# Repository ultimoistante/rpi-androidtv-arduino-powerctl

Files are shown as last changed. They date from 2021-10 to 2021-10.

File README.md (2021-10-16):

# RaspberryPi 4 Android TV with Arduino-based PowerController
This repository contains the source code, all schematics and some words on the build process of a custom AndroidTV device I've built with a RaspberryPi4 SBC, an Arduino Nano, and a case of an old Technicolor TG582n ADSL modem.

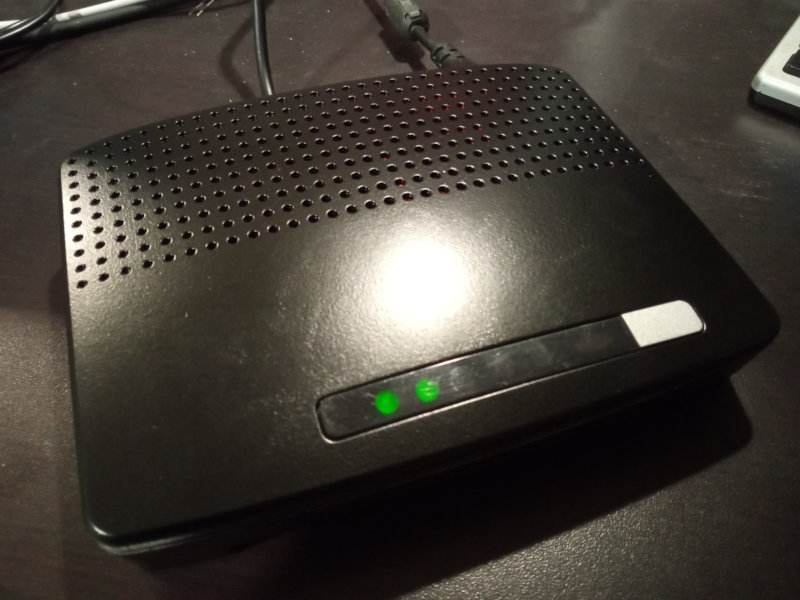
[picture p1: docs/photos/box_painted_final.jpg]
final version final painted box


## Arduino PowerController features
- handles RaspberryPi power via relay;
- does case cooling controlling a fan with PWM, reading temperature with a thermistor;
- since it's connected to RaspberryPi via UART, it can detect when android system is full booted, and can send shutdown command to it when user presses power button. After some seconds, cuts RaspberryPi power deactivating relay;
- drives the leds on the original modem board using different patterns for standby, booting and shutdown phases (I've reused a slice of the original modem pcb, cut with a grinder);

## Arduino code
The arduino code is very simple, and is built with PlatformIO on VisualStudio Code. All the code is in src/main.cpp.
I tried to do my best to make code very clean and simple, and with full comments.

## AndroidTV system setup
I've downloaded and installed LineageOS 18.1 Android TV (Android 11) (by KonstaGANG): https://konstakang.com/devices/rpi4/LineageOS18-ATV/
I've installed it on a 32GB microSD.

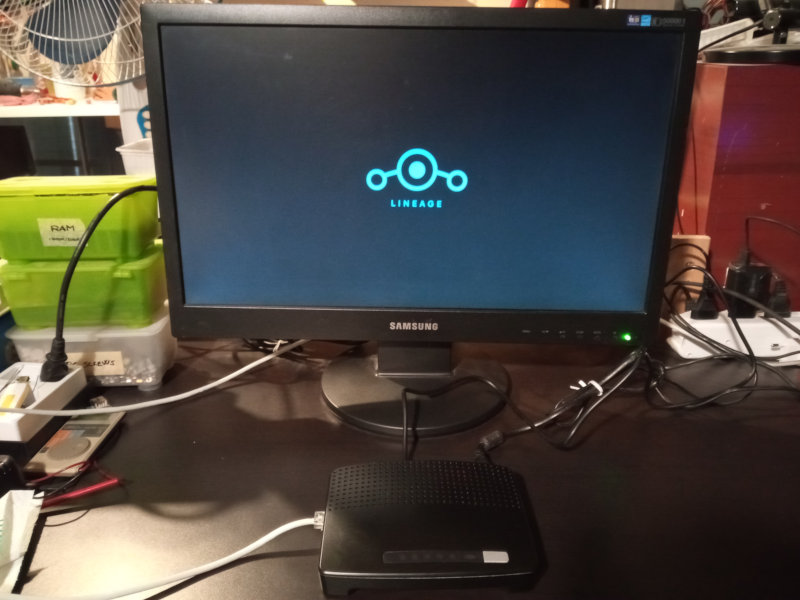
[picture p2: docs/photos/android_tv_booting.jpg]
android-tv booting

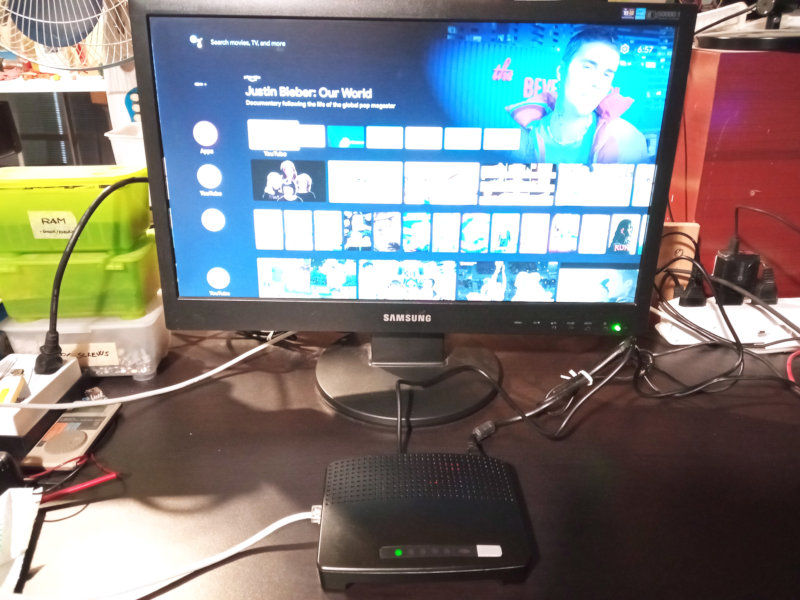
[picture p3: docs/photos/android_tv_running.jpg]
android-tv running


## Case adaptations
I had this old modem, found some time ago in local dumpster. It's perfect for my needs (right dimensions, nice looking design, and many ventilation holes, all around case).

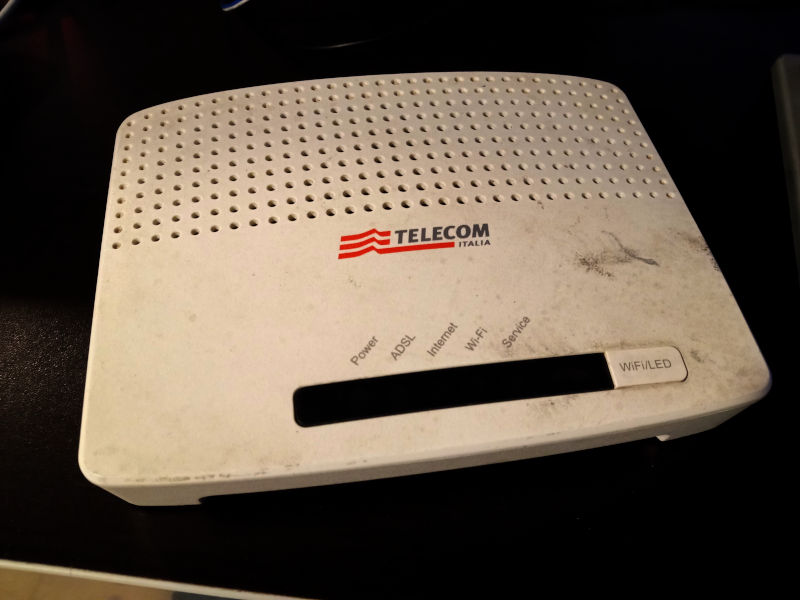
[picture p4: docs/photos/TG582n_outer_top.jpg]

*case donor device, an old Technicolor TG582n, coming from the dumpster*

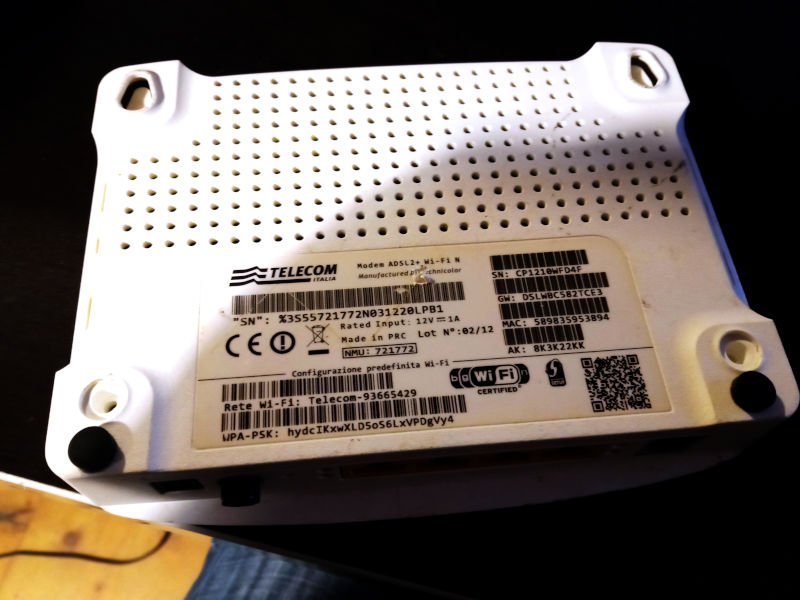
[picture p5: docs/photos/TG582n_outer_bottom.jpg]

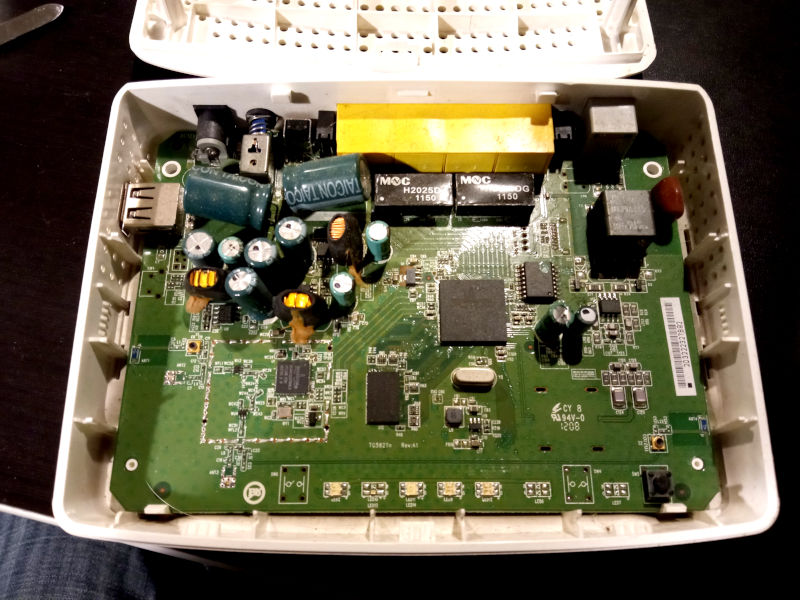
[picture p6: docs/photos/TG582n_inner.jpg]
device inner pcb

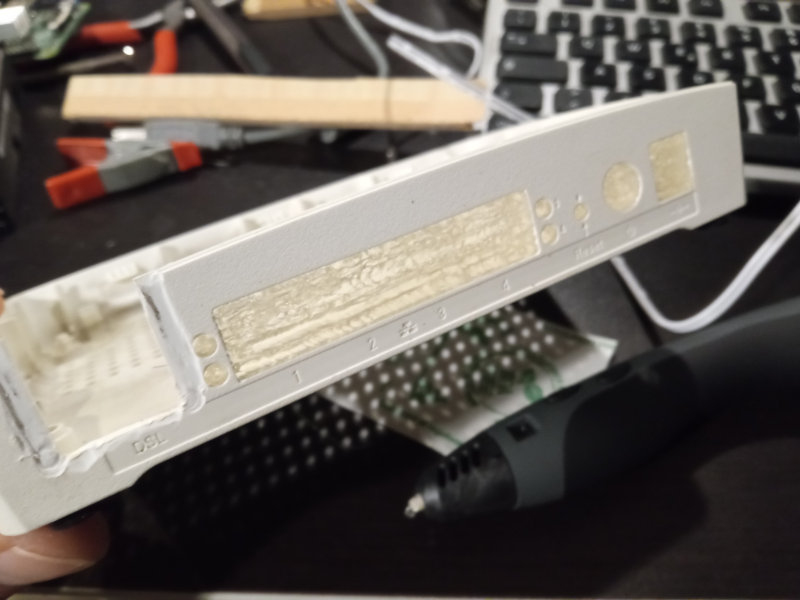
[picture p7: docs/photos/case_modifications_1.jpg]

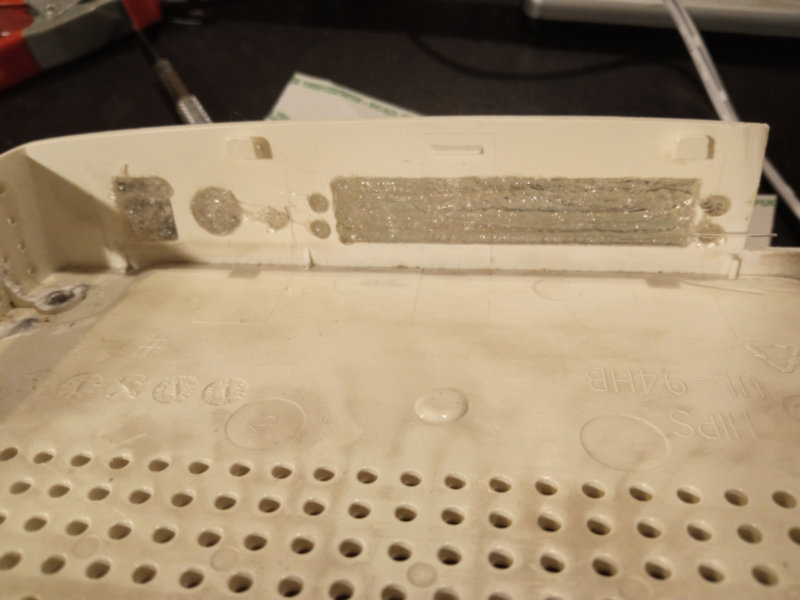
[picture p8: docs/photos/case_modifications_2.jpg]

*filled unneeded holes with a 3D pen*
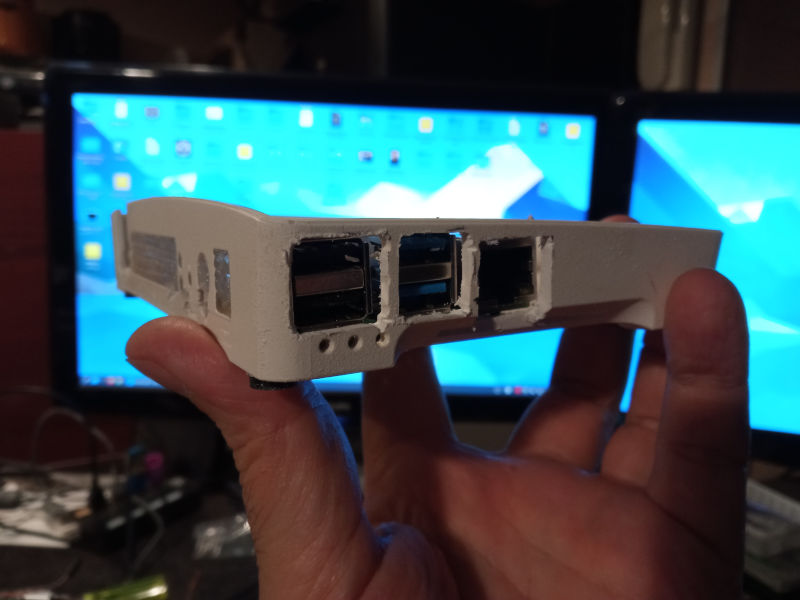
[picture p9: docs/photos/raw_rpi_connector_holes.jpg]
raw rpi connetor holes

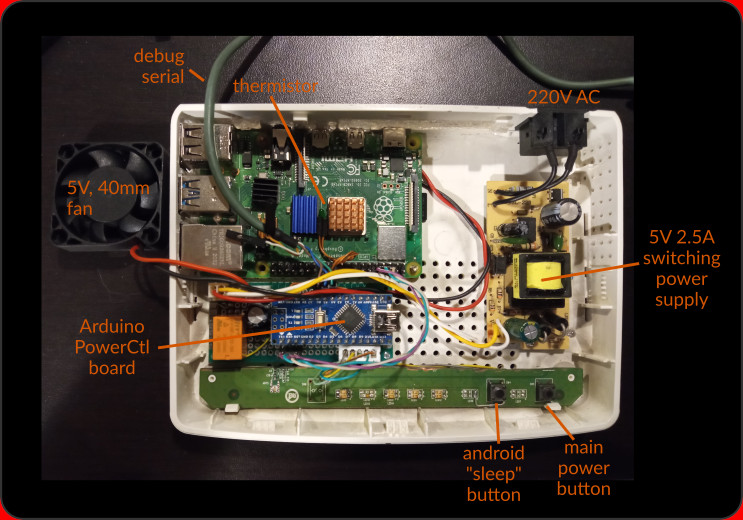
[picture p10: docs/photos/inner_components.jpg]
inner view

*NOTE: android sleep button is connected to GPIO21/GND on RaspberryPi. Sorry, not shown in photo. See FAQs on konstaGANG page)*
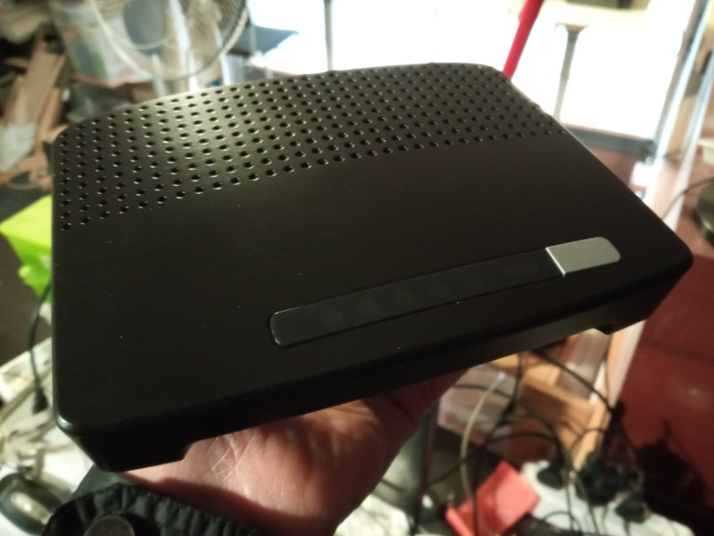
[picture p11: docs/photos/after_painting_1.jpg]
after painting

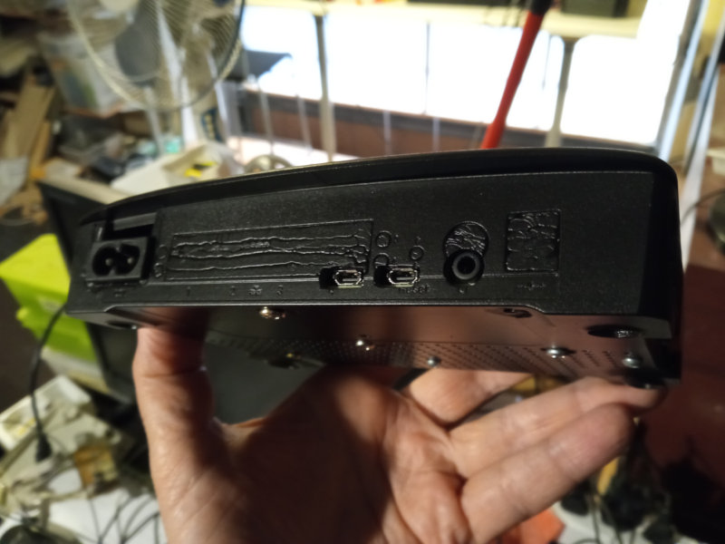
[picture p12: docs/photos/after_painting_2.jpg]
after painting


### Original modem PCB modifications
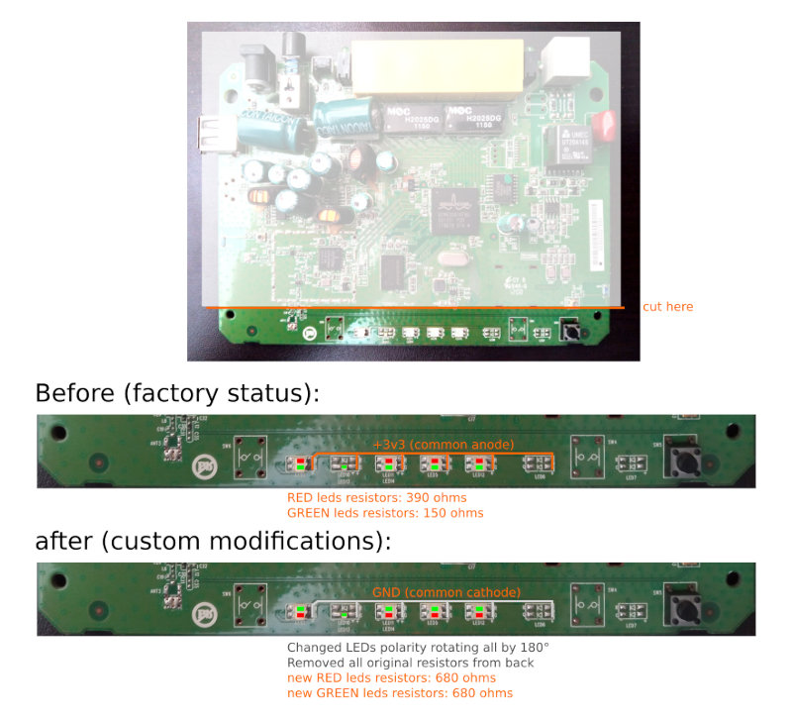
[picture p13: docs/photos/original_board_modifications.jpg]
original board modifications


### Complete circuit schematics
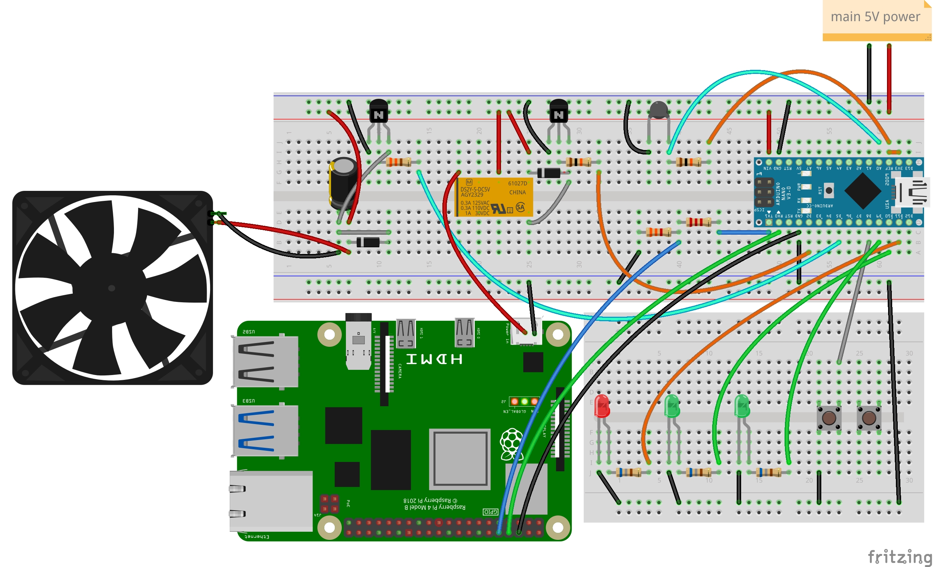
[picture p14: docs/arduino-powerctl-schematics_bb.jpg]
complete schematics

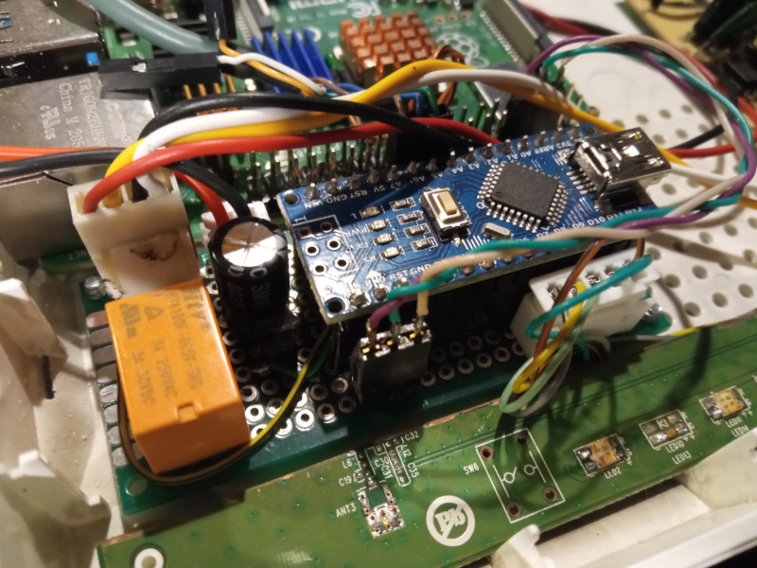
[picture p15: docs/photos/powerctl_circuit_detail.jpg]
powerctl board

Note:
 - for fan control, i've used a C2001 NPN transistor (Ic=700mA), and capacitor is 1000uF 16V (to avoid pwm audible noise);
 - relay is 5V 3A, driver transistor is a generic NPN (i.e: BC547);
 - thermistor is a 10K type;
 - on Arduino TX there is a level converter made with a voltage divider (R1: 2k2, R2: 3k3), to avoid damage on RaspberryPi UART;

(fritzing and pdf files are under docs/ directory)

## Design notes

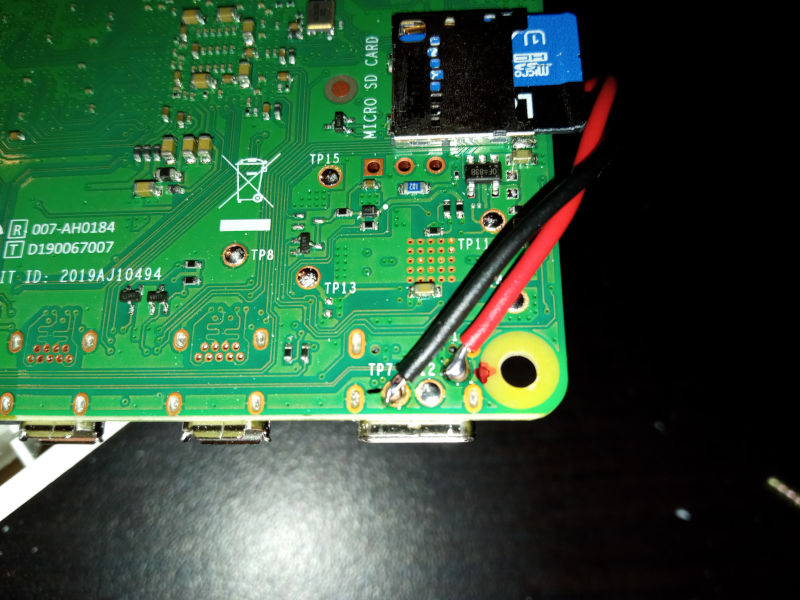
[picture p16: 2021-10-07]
docs/photos/rpi4_power_pads.jpg

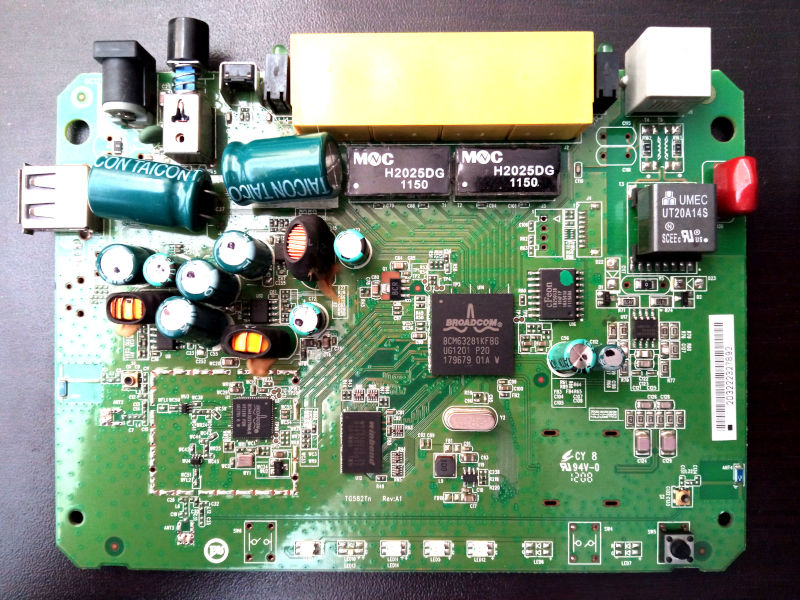
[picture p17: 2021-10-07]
docs/photos/TG582n_board.jpg

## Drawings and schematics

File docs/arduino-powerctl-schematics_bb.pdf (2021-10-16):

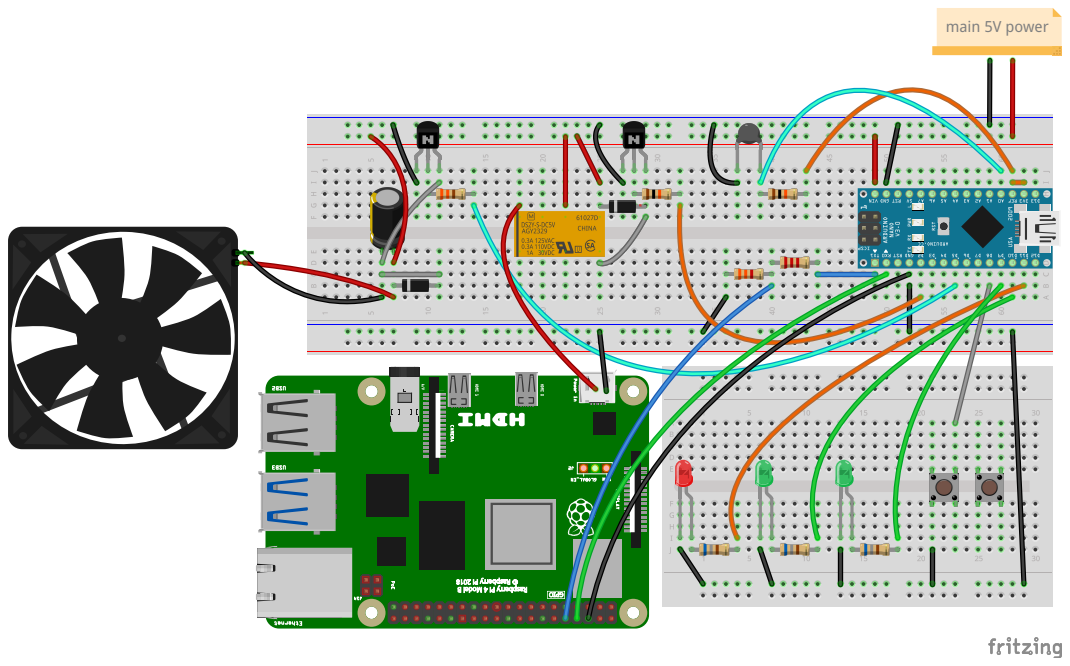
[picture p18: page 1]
main 5V power

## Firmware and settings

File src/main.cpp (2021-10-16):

/** RaspberryPi/AndroidTV Arduino Power Control device
 **
 ** This device implements power control features for RaspberryPi4 AndroidTV mediacenter.
 ** Its main feature is to control power supply to RaspberryPi through a relay.
 ** Communicates with RaspberryPi via UART connection, sending commands (i.e.: shutdown).
 ** It also controls case fan throttling reading RaspberryPi CPU temperature using a thermistor.
 **
 ** Author: Salvatore Carotenuto of OpenMakersItaly, aka ultimoistante
 **
 ** Credits:
 **   Temperature reading code taken from: https://learn.adafruit.com/thermistor/using-a-thermistor
 **/

 // -----------------------------------------------------------------------------
 // -----------------------------------------------------------------------------
 //
 // Arduino Nano connections
 //                                       +-----+
 //                                 +-----|=====|-----+
 //                      D13 [PB5]  |o    |=====|    o|  [PB4] D12
 //                            3v3  |o    +-----+    o| ~[PB3] D11 ---> (standby) status LED (red)
 //                           Vref  |o               o| ~[PB2] D10 ---> (power on) status LED (green)
 //       thermistor <--- A0 [PC0]  |o               o| ~[PB1] D9  ---> serial activity LED
 //                       A1 [PC1]  |o               o|  [PB0] D8  ---> power button
 //                       A2 [PC2]  |o               o|  [PD7] D7  
 //                       A3 [PC3]  |o    Arduino    o| ~[PD6] D6
 //  debug serial RX <--- A4 [PC4]  |o      Nano     o| ~[PD5] D5  ---> fan speed throttle
 //  debug serial TX <--- A5 [PC5]  |o               o|  [PD4] D4  
 //                      A6 [ADC6]  |o               o| ~[PD3] D3  
 //                      A7 [ADC7]  |o               o|  [PD2] D2  ---> RaspberryPi power relay control
 //                             5V  |o               o|  GND
 //                      RST [PC6]  |o               o|  [PC6] RST
 //                            GND  |o     . . .     o|  [PD0] RX  ---> to RaspberryPi TXD (pin  8 - GPIO14)
 //                            Vin  |o     . . .     o|  [PD1] TX  ---> to RaspberryPi RXD (pin 10 - GPIO15)
 //                                 +-----------------+
 //
 // -----------------------------------------------------------------------------
 // -----------------------------------------------------------------------------


#include <Arduino.h>
#include <SoftwareSerial.h>
#include <AceButton.h>
using namespace ace_button;
#include <jled.h>


// -----------------------------------------------------------------------------


#define THERMISTOR_PIN                A0
#define STATUS_LED_RED_PIN            11
#define STATUS_LED_GREEN_PIN          10
#define UART_ACT_LED_PIN              9
#define POWER_BUTTON_PIN              8
#define FAN_THROTTLE_PIN              5
#define RELAY_PIN                     2
#define SW_SERIAL_RX_PIN              A4
#define SW_SERIAL_TX_PIN              A5

#define THERMISTOR_SERIES_RESISTOR    10000 // the value of the 'other' resistor in voltage divider
#define THERMISTOR_NOMINAL_R          10000 // nominal thermistor resistance at 25 degrees C
#define THERMISTOR_NOMINAL_TEMP       25    // thermistor nominal resistance temperature (almost always 25 C)
#define THERMISTOR_BETA_COEFFICIENT   3950  // thermistor beta coefficient (usually 3000-4000)
#define TEMPERATURE_READ_SAMPLES      5     // how many samples to take and average, more takes longer, but is more 'smooth'

#define HW_SERIAL_BAUDRATE            115200
#define SW_SERIAL_BAUDRATE            57600

// uncomment this line to dump android serial on debug serial
// #define DUMP_TO_DEBUG_SERIAL

#define READ_TEMPERATURE_INTERVAL           2500
#define FAN_THROTTLE_MIN_TEMP               30.0
#define FAN_THROTTLE_MIN_TEMP_HYSTERESIS    2.0
#define FAN_THROTTLE_MAX_TEMP               50.0
#define FAN_THROTTLE_MIN_PWM                16
#define FAN_THROTTLE_MAX_PWM                255
float currentTemperature = 0;
unsigned long next_read_temperature_time = 0;
unsigned char fan_was_activated = 0;

#define POWER_BUTTON_LONGPRESS_DELAY        2000

#define SHUTDOWN_GRACE_TIME_MSECS           10000

#define STATUS_STANDBY                  0
#define STATUS_BOOTING                  1
#define STATUS_ON                       2
#define STATUS_SHUTDOWN                 3
unsigned char currentStatus = STATUS_STANDBY;

// these are the strings to wait from android boot log, to detect when device is full booted.
// Arduino device goes in "STATUS_ON" when receives one of these strings.
#define ANDROID_BOOT_COMPLETE_LOG_LINE      "sdcardfs: dev_name -> /data/media"
#define ANDROID_BOOT_COMPLETE_LOG_LINE_ALT  "app=com.google.android.apps.mediashell"
// this is the string to wait from android boot log, to detect when device has completed shutdown
#define ANDROID_SHUTDOWN_COMPLETE_LOG_LINE  "reboot: Power down"

// debug (software) serial
SoftwareSerial debugSerial(SW_SERIAL_RX_PIN, SW_SERIAL_TX_PIN); // RX, TX

// status leds
auto standbyStatusLed = JLed(STATUS_LED_RED_PIN);
auto poweronStatusLed = JLed(STATUS_LED_GREEN_PIN);

// power button
AceButton powerButton(POWER_BUTTON_PIN);

#define MAX_SERIAL_BUFFER   511
char serialBuffer[MAX_SERIAL_BUFFER + 1];
unsigned int serialBufferIndex = 0;

volatile unsigned char interruptCounter = 0;

unsigned long shutdown_grace_time = 0;


// ----------------------------------------------------------------------------


// Interrupt handler called once a millisecond
SIGNAL(TIMER0_COMPA_vect)
    {
    interruptCounter++;
    if (interruptCounter == 50) // updates leds every 50msecs
        {
        standbyStatusLed.Update();
        poweronStatusLed.Update();
        interruptCounter = 0;
        }
    }


// ----------------------------------------------------------------------------


float readTemperature()
    {
    float average = 0.0;
    // take N samples in a row, with a slight delay
    for (uint8_t i = 0; i < TEMPERATURE_READ_SAMPLES; i++)
        {
        average += analogRead(THERMISTOR_PIN);
        delay(10);
        }
    average /= TEMPERATURE_READ_SAMPLES;

    // convert the value to resistance
    average = 1023 / average - 1;
    average = THERMISTOR_SERIES_RESISTOR / average;

    float steinhart;
    steinhart = average / THERMISTOR_NOMINAL_R;            // (R/Ro)
    steinhart = log(steinhart);                            // ln(R/Ro)
    steinhart /= THERMISTOR_BETA_COEFFICIENT;              // 1/B * ln(R/Ro)
    steinhart += 1.0 / (THERMISTOR_NOMINAL_TEMP + 273.15); // + (1/To)
    steinhart = 1.0 / steinhart;                           // Invert
    steinhart -= 273.15;                                   // convert absolute temp to C
    //
    return steinhart;
    }



// ----------------------------------------------------------------------------


// computes fan pwm value, based on temperature read. Also handles shutdown hysteresis.
// Temperature to PWM mapping is similar to arduino "map" function:
//    long map(long x, long in_min, long in_max, long out_min, long out_max) {
//        return (x - in_min) * (out_max - out_min) / (in_max - in_min) + out_min;
//    }
// 
unsigned char computeFanPwm(float temperature)
    {
    unsigned char pwmValue = 0;
    float minTemp = fan_was_activated ? (FAN_THROTTLE_MIN_TEMP - FAN_THROTTLE_MIN_TEMP_HYSTERESIS) : FAN_THROTTLE_MIN_TEMP;
    float maxTemp = FAN_THROTTLE_MAX_TEMP;
    //
    if (temperature <= minTemp)
        {
        pwmValue = 0;
        fan_was_activated = 0;
        }
    else
        {
        fan_was_activated = 1;
        //
        if (temperature >= maxTemp)
            pwmValue = FAN_THROTTLE_MAX_PWM;
        else
            {
            if (temperature > minTemp && temperature < maxTemp)
                {
                float mappedValue = (temperature - minTemp) * (FAN_THROTTLE_MAX_PWM - FAN_THROTTLE_MIN_PWM) / (maxTemp - minTemp) + FAN_THROTTLE_MIN_PWM;
                pwmValue = int(mappedValue);
                }
            }
        }
    //
    return pwmValue;
    }


// ----------------------------------------------------------------------------


void updateCurrentStatus(unsigned char newStatus)
    {
    currentStatus = newStatus;
    switch (currentStatus)
        {
            case STATUS_STANDBY:
                standbyStatusLed.Breathe(5000).Forever();
                poweronStatusLed.Off();
                digitalWrite(RELAY_PIN, LOW);
                break;
            case STATUS_BOOTING:
                standbyStatusLed.Blink(25, 250).Forever();
                poweronStatusLed.Blink(25, 250).Forever();
                digitalWrite(RELAY_PIN, HIGH);
                break;
            case STATUS_ON:
                standbyStatusLed.Off();
                poweronStatusLed.Breathe(2000).Forever();
                break;
            case STATUS_SHUTDOWN:
                standbyStatusLed.Blink(25, 250).Forever();
                poweronStatusLed.Off();
                // sends shutdown command to android device
                Serial.println("reboot -p");
                break;
        }
    }


// -----------------------------------------------------------------------------


void handleButtonEvent(AceButton* button, uint8_t eventType, uint8_t /*buttonState*/)
    {
    switch (eventType)
        {
        // handles "released" event as a "pressed" event, to distiguish it from a "long pressed" event
            case AceButton::kEventReleased:
                debugSerial.println("[I] button pressed");
                if (currentStatus == STATUS_STANDBY)
                    updateCurrentStatus(STATUS_BOOTING);
                else if (currentStatus == STATUS_ON)
                    updateCurrentStatus(STATUS_SHUTDOWN);
                break;
                // 
            // handles "long pressed" event
            case AceButton::kEventLongPressed:
                debugSerial.println("[I] button LONG pressed");
                // emergency shutdown: returns to STATUS_STANDBY (deactivates relay)
                if (currentStatus != STATUS_STANDBY)
                    updateCurrentStatus(STATUS_STANDBY);
                break;
        }
    }


// ----------------------------------------------------------------------------



void setup()
    {
    // for more stable readings, AREF pin is connected to 3.3V, so we set analogReference to EXTERNAL
    analogReference(EXTERNAL);
    //
    // sets USER_BUTTON_PIN as input, with pullup
    pinMode(POWER_BUTTON_PIN, INPUT_PULLUP);
    //
    // sets FAN_THROTTLE_PIN to output
    pinMode(FAN_THROTTLE_PIN, OUTPUT);
    //
    // sets RELAY_PIN mode to output, and low
    pinMode(RELAY_PIN, OUTPUT);
    digitalWrite(RELAY_PIN, LOW);
    //
    pinMode(UART_ACT_LED_PIN, OUTPUT);
    //
    // enables interrupt on "Compare A" function of Timer0 (already used for millis())
    OCR0A = 0xAF;
    TIMSK0 |= _BV(OCIE0A);
    //
    // user button configuration
    ButtonConfig* buttonConfig = ButtonConfig::getSystemButtonConfig();
    buttonConfig->setEventHandler(handleButtonEvent);
    buttonConfig->setFeature(ButtonConfig::kFeatureLongPress);
    buttonConfig->setFeature(ButtonConfig::kFeatureSuppressAfterLongPress);
    buttonConfig->setLongPressDelay(POWER_BUTTON_LONGPRESS_DELAY);
    //
    // starts hardware serial (connected to RaspberryPi serial)
    Serial.begin(HW_SERIAL_BAUDRATE);
    // starts software (debug) serial
    debugSerial.begin(SW_SERIAL_BAUDRATE);
    //
    // initializes device status
    updateCurrentStatus(STATUS_STANDBY);
    //
    debugSerial.println("[I] device ready");
    }


// ----------------------------------------------------------------------------


void loop()
    {
    unsigned long now = millis();
    char c;
    //
    //
    // if we have requested shutdown, checks if passed shutdown grace time
    if (shutdown_grace_time && now >= shutdown_grace_time)
        {
        updateCurrentStatus(STATUS_STANDBY);
        shutdown_grace_time = 0;
        }
    //
    //
    // handles reading from android serial 
    while (Serial.available())
        {
        digitalWrite(UART_ACT_LED_PIN, HIGH);
        c = Serial.read();
        if (c != '\r' && c != '\n')
            {
            serialBuffer[serialBufferIndex] = c;
            serialBuffer[serialBufferIndex + 1] = '\0';
            if (serialBufferIndex < MAX_SERIAL_BUFFER)
                serialBufferIndex++;
            }
        else
            {
#ifdef DUMP_TO_DEBUG_SERIAL
            debugSerial.println(serialBuffer);
#endif
            // if android is booting, waits for log line dumped on boot complete
            if (currentStatus == STATUS_BOOTING)
                {
                if (strstr(serialBuffer, ANDROID_BOOT_COMPLETE_LOG_LINE) != NULL || strstr(serialBuffer, ANDROID_BOOT_COMPLETE_LOG_LINE_ALT) != NULL)
                    updateCurrentStatus(STATUS_ON);
                }

            // if android is doing shutdown, waits for log line dumped on shutdown complete
            if (currentStatus == STATUS_SHUTDOWN)
                {
                if (strstr(serialBuffer, ANDROID_SHUTDOWN_COMPLETE_LOG_LINE) != NULL)
                    shutdown_grace_time = now + SHUTDOWN_GRACE_TIME_MSECS;
                }

            serialBufferIndex = 0;
            }
        }
    digitalWrite(UART_ACT_LED_PIN, LOW);
    //
    //
    // reads temperature and handles fan pwm
    if (now >= next_read_temperature_time)
        {
        currentTemperature = readTemperature();
        unsigned char pwmValue = computeFanPwm(currentTemperature);
        analogWrite(FAN_THROTTLE_PIN, pwmValue);
        //
        debugSerial.print("[I] T: ");
        debugSerial.print(currentTemperature);
        debugSerial.print(" *C - pwm: ");
        debugSerial.println(pwmValue);
        //
        next_read_temperature_time = millis() + READ_TEMPERATURE_INTERVAL;
        }
    //
    //
    // updates user button status
    powerButton.check();
    }


// ----------------------------------------------------------------------------

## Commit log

2021-10-08 improved fan control; added button longpress; code cleaning;
2021-10-16 documentation update
    [arduino-powerctl-schematics.fzz]
